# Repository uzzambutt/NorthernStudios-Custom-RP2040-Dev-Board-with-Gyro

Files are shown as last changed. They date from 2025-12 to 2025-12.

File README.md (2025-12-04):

# NorthernStudios-Custom-RP2040-Dev-Board-with-Gyro

***Schematic***
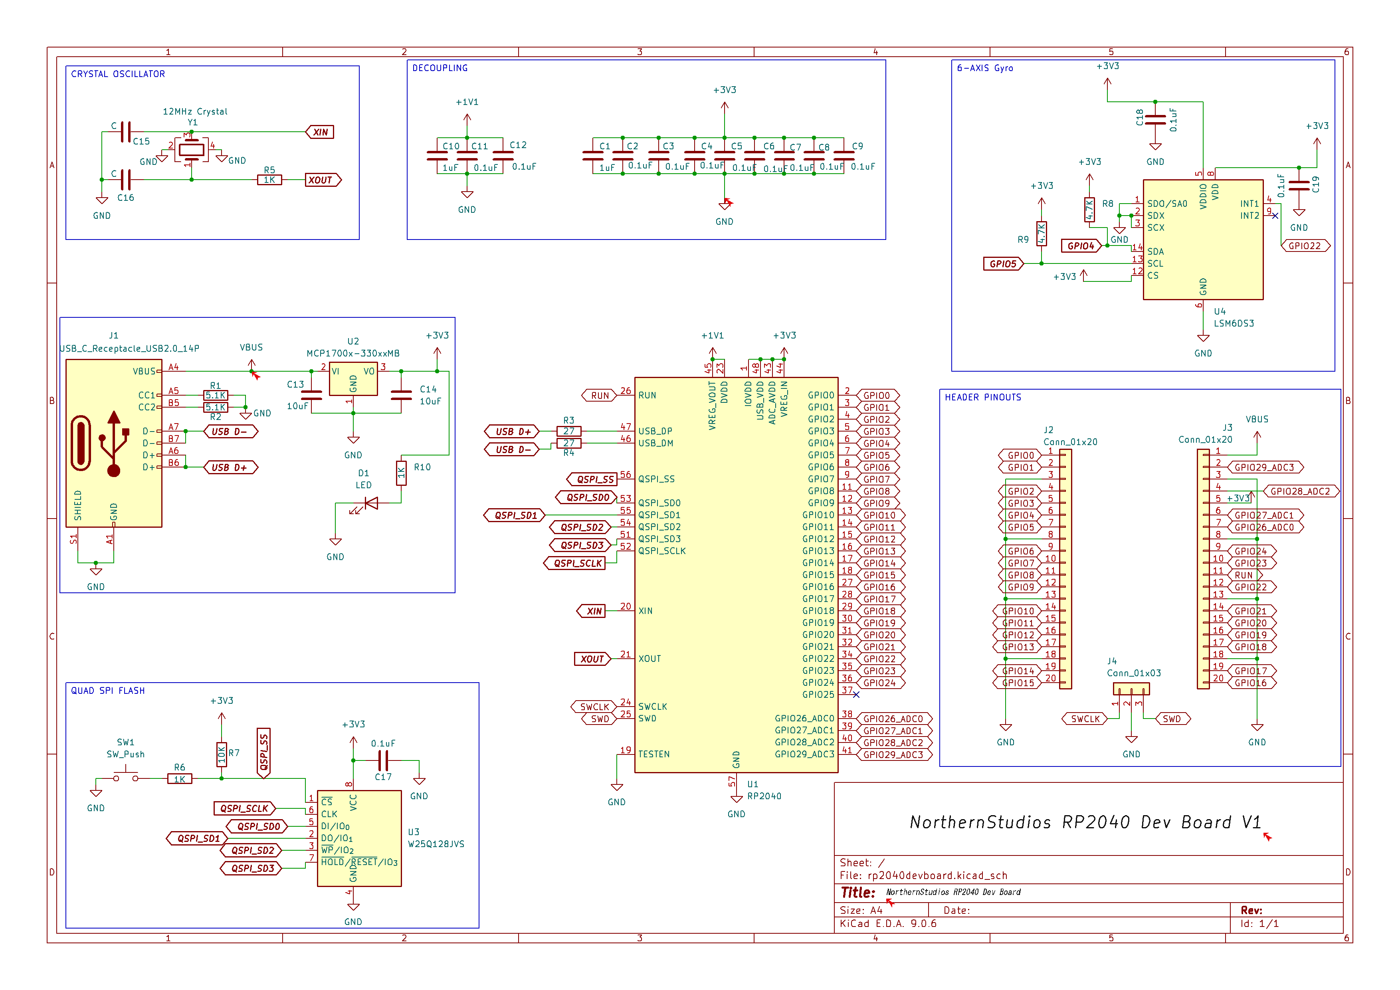
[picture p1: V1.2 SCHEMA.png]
Schematic


## Images:
**Rendered Board**:
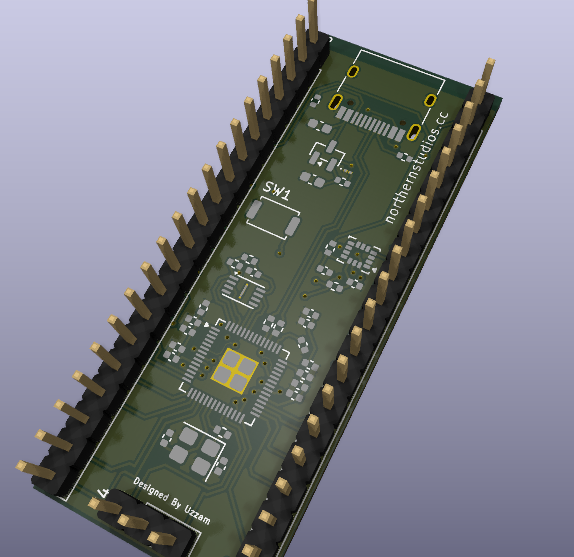
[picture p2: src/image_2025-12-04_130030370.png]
Rendered


**Raw Routing**:
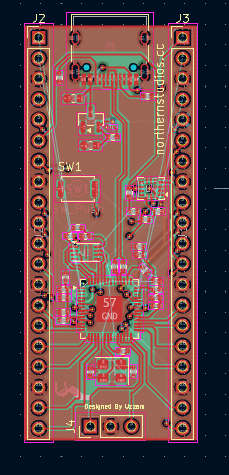
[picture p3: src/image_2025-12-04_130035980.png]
Routing


## Features
1: This dev board has a LED for power indicator.
2: This board has a 6-Axis Gyro + Accelerometer integrated in it. you can read the schematic to check it out.

## Caution:
> I have not routed the GPIO 0,1 and ADC 1 and 2 because of spacing problems. there was not enough space to route them because the accelerometer had covered most of that space. 

---
> Made By uzzam for NorthernStudios.
> Funded By HackClub.
> 04/12/2025
> uzzambutt1@outlook.com

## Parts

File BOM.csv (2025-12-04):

Reference | Qty | Value | DNP | Exclude from BOM | Exclude from Board | Footprint | Datasheet
C1,C10 | 2 | 1uF |  |  |  | Capacitor_SMD:C_0402_1005Metric | ~
C2,C3,C4,C5,C6,C7,C8,C9,C11,C12,C17,C18,C19 | 13 | 0.1uF |  |  |  | Capacitor_SMD:C_0402_1005Metric | ~
C13,C14 | 2 | 10uF |  |  |  | Capacitor_SMD:C_0603_1608Metric | ~
C15,C16 | 2 | 33pF |  |  |  | Capacitor_SMD:C_0402_1005Metric | ~
D1 | 1 | LED |  |  |  | LED_SMD:LED_01005_0402Metric | ~
J1 | 1 | USB_C_Receptacle_USB2.0_14P |  |  |  | Connector_USB:USB_C_Receptacle_HRO_TYPE-C-31-M-12 | https://www.usb.org/sites/default/files/documents/usb_type-c.zip
J2,J3 | 2 | Conn_01x20 |  |  |  | Connector_PinHeader_2.54mm:PinHeader_1x20_P2.54mm_Vertical | ~
J4 | 1 | Conn_01x03 |  |  |  | Connector_PinHeader_2.54mm:PinHeader_1x03_P2.54mm_Vertical | ~
R1,R2 | 2 | 5.1K |  |  |  | Resistor_SMD:R_0402_1005Metric | ~
R3,R4 | 2 | 27 |  |  |  | Resistor_SMD:R_0402_1005Metric | ~
R5,R6,R10 | 3 | 1K |  |  |  | Resistor_SMD:R_0402_1005Metric | ~
R7 | 1 | 10K |  |  |  | Resistor_SMD:R_0402_1005Metric | ~
R8,R9 | 2 | 4.7K |  |  |  | Resistor_SMD:R_0402_1005Metric | ~
SW1 | 1 | SW_Push |  |  |  | Button_Switch_SMD:SW_Push_SPST_NO_Alps_SKRK | ~
U1 | 1 | RP2040 |  |  |  | Package_DFN_QFN:QFN-56-1EP_7x7mm_P0.4mm_EP3.2x3.2mm | https://datasheets.raspberrypi.com/rp2040/rp2040-datasheet.pdf
U3 | 1 | W25Q16JVZPIQ TR |  |  |  | Package_SON:Winbond_USON-8-1EP_3x2mm_P0.5mm_EP0.2x1.6mm | https://www.winbond.com/resource-files/w25q128jv_dtr%20revc%2003272018%20plus.pdf
U4 | 1 | LSM6DS3 |  |  |  | Package_LGA:LGA-14_3x2.5mm_P0.5mm_LayoutBorder3x4y | https://www.st.com/resource/en/datasheet/lsm6ds3tr-c.pdf
U5 | 1 | MCP1700x-330xxTT |  |  |  | Package_TO_SOT_SMD:SOT-23 | http://ww1.microchip.com/downloads/en/DeviceDoc/20001826D.pdf
Y1 | 1 | 12MHz Crystal |  |  |  | Crystal:Crystal_SMD_3225-4Pin_3.2x2.5mm | ~

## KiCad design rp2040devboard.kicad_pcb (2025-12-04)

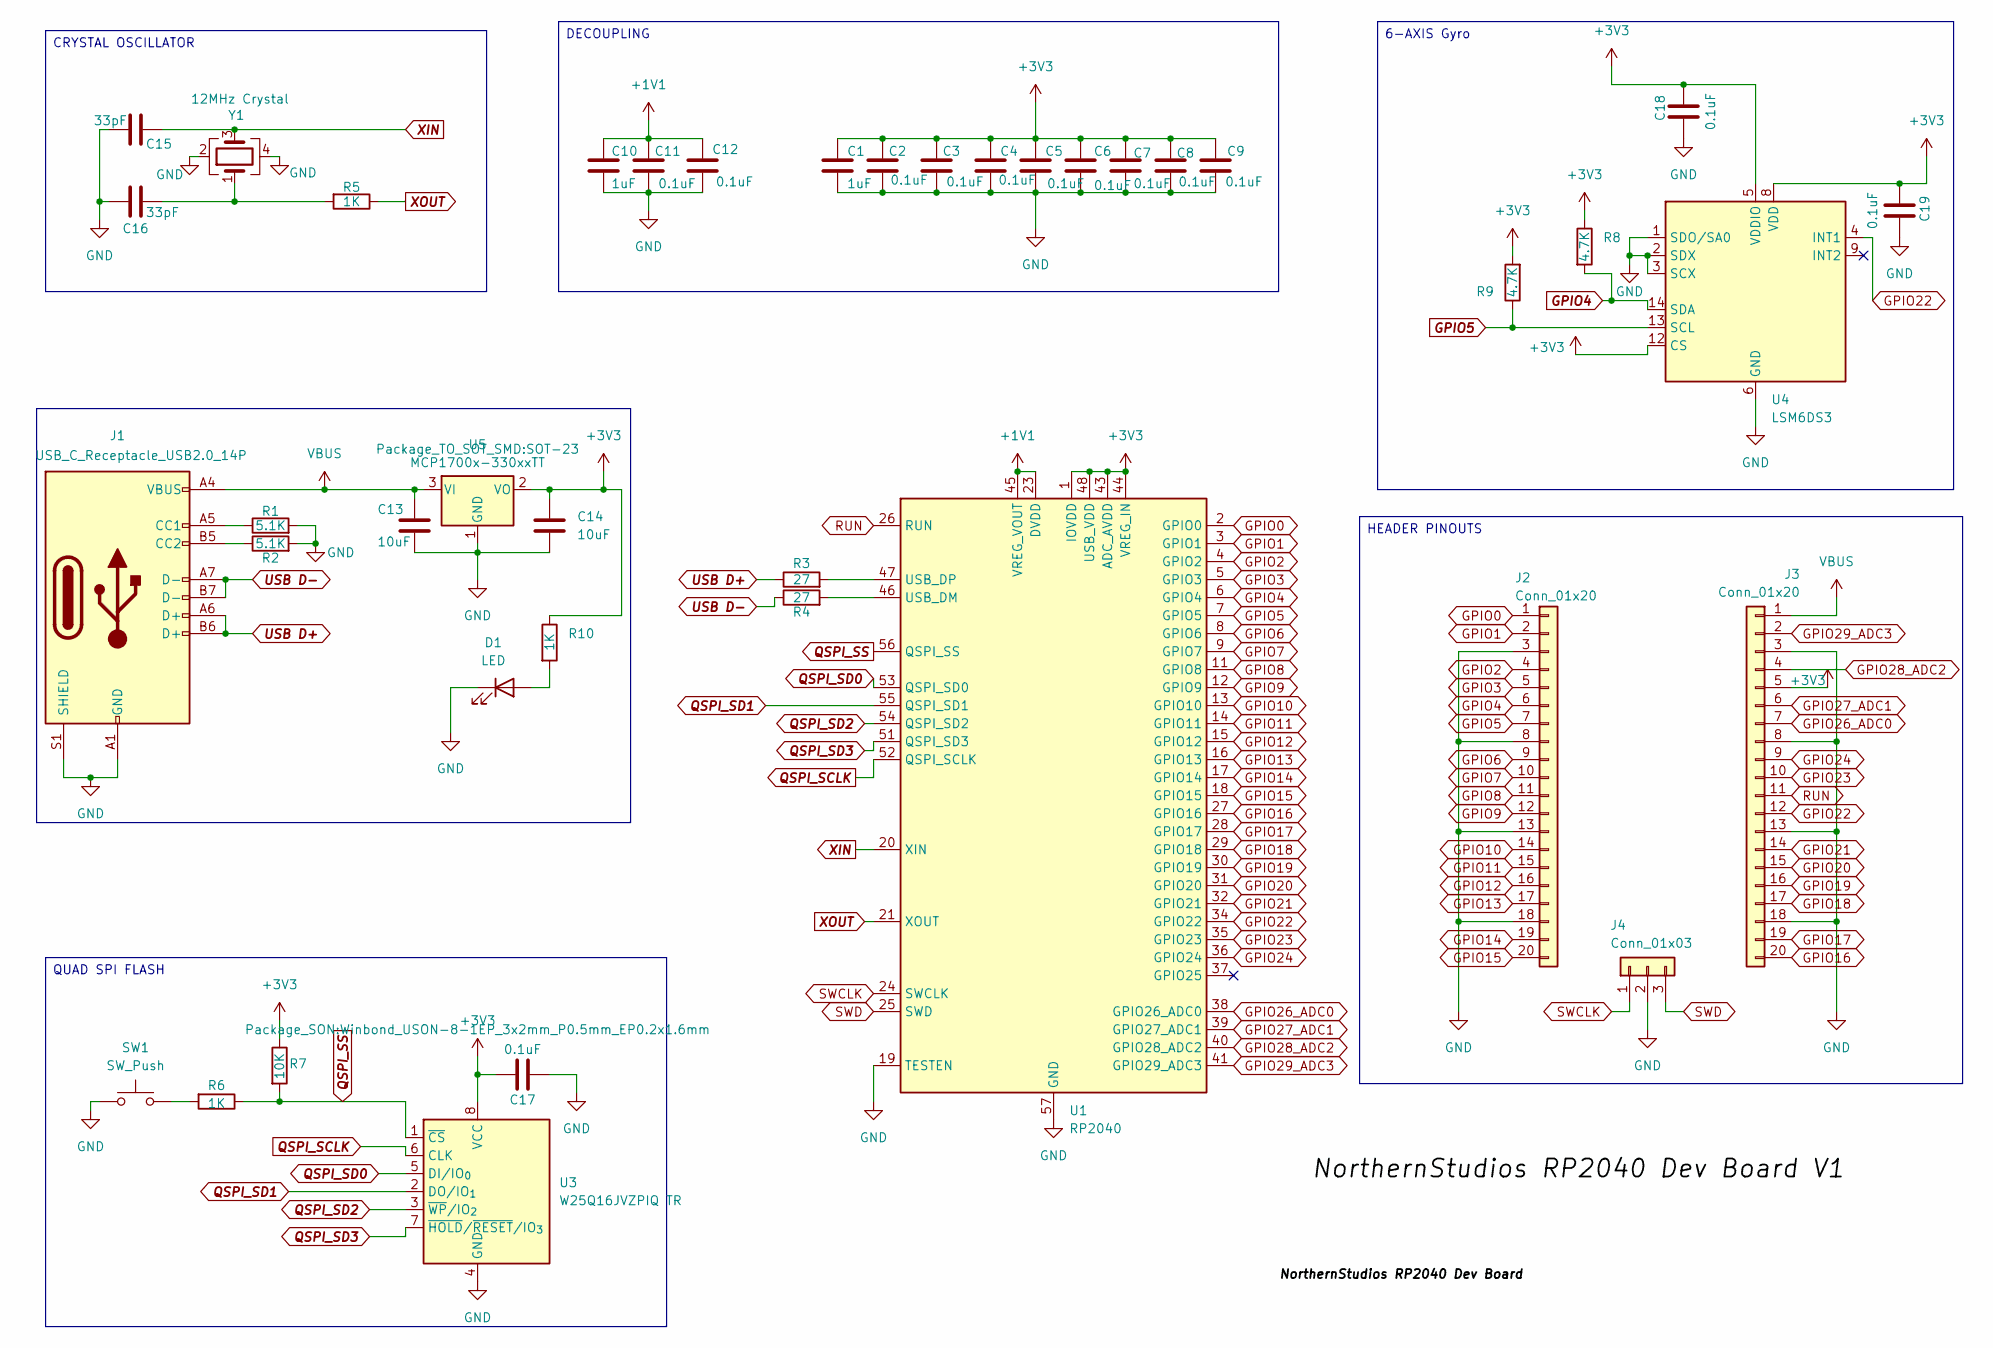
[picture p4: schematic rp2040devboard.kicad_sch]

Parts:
C1, C10: 1uF; C_0402_1005Metric
C2, C3, C4, C5, C6, C7, C8, C9, C11, C12, C17, C18, C19: 0.1uF; C_0402_1005Metric
C13, C14: 10uF; C_0603_1608Metric
C15, C16: 33pF; C_0402_1005Metric
D1: LED; LED_01005_0402Metric
J1: USB_C_Receptacle_USB2.0_14P; USB_C_Receptacle_HRO_TYPE-C-31-M-12
J2, J3: Conn_01x20; PinHeader_1x20_P2.54mm_Vertical
J4: Conn_01x03; PinHeader_1x03_P2.54mm_Vertical
R1, R2: 5.1K; R_0402_1005Metric
R3, R4: 27; R_0402_1005Metric
R5, R6, R10: 1K; R_0402_1005Metric
R7: 10K; R_0402_1005Metric
R8, R9: 4.7K; R_0402_1005Metric
SW1: SW_Push; SW_Push_SPST_NO_Alps_SKRK
U1: RP2040; QFN-56-1EP_7x7mm_P0.4mm_EP3.2x3.2mm
U3: W25Q16JVZPIQ TR; Winbond_USON-8-1EP_3x2mm_P0.5mm_EP0.2x1.6mm
U4: LSM6DS3; LGA-14_3x2.5mm_P0.5mm_LayoutBorder3x4y
U5: MCP1700x-330xxTT; SOT-23
Y1: 12MHz Crystal; Crystal_SMD_3225-4Pin_3.2x2.5mm

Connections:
+1V1: C10.1, C11.1, C12.1, U1.23 (DVDD), U1.45 (VREG_VOUT), U1.50 (DVDD)
+3V3: C1.1, C2.1, C3.1, C4.1, C5.1, C6.1, C7.1, C8.1, C9.1, C14.1, C17.1, C18.1, C19.2, J3.5, R7.1, R8.1, R9.2, R10.1, U1.1 (IOVDD), U1.10 (IOVDD), U1.22 (IOVDD), U1.33 (IOVDD), U1.42 (IOVDD), U1.43 (ADC_AVDD), U1.44 (VREG_IN), U1.48 (USB_VDD), U1.49 (IOVDD), U3.8 (VCC), U4.5 (VDDIO), U4.8 (VDD), U4.12 (CS), U5.2 (VO)
GND: C1.2, C2.2, C3.2, C4.2, C5.2, C6.2, C7.2, C8.2, C9.2, C10.2, C11.2, C12.2, C13.1, C14.2, C15.1, C16.1, C17.2, C18.2, C19.1, D1.1 (K), J1.A1 (GND), J1.A12 (GND), J1.B1 (GND), J1.B12 (GND), J1.S1 (SHIELD), J2.3, J2.8, J2.13, J2.18, J3.3, J3.8, J3.13, J3.18, J4.2, R1.2, R2.2, SW1.1, U1.19 (TESTEN), U1.57 (GND), U3.4 (GND), U4.1 (SDO/SA0), U4.2 (SDX), U4.3 (SCX), U4.6 (GND), U4.7 (GND), U5.1 (GND), Y1.2, Y1.4
GPIO0: J2.1, U1.2 (GPIO0)
GPIO1: J2.2, U1.3 (GPIO1)
GPIO2: J2.4, U1.4 (GPIO2)
GPIO3: J2.5, U1.5 (GPIO3)
GPIO4: J2.6, R8.2, U1.6 (GPIO4), U4.14 (SDA)
GPIO5: J2.7, R9.1, U1.7 (GPIO5), U4.13 (SCL)
GPIO6: J2.9, U1.8 (GPIO6)
GPIO7: J2.10, U1.9 (GPIO7)
GPIO8: J2.11, U1.11 (GPIO8)
GPIO9: J2.12, U1.12 (GPIO9)
GPIO10: J2.14, U1.13 (GPIO10)
GPIO11: J2.15, U1.14 (GPIO11)
GPIO12: J2.16, U1.15 (GPIO12)
GPIO13: J2.17, U1.16 (GPIO13)
GPIO14: J2.19, U1.17 (GPIO14)
GPIO15: J2.20, U1.18 (GPIO15)
GPIO16: J3.20, U1.27 (GPIO16)
GPIO17: J3.19, U1.28 (GPIO17)
GPIO18: J3.17, U1.29 (GPIO18)
GPIO19: J3.16, U1.30 (GPIO19)
GPIO20: J3.15, U1.31 (GPIO20)
GPIO21: J3.14, U1.32 (GPIO21)
GPIO22: J3.12, U1.34 (GPIO22), U4.4 (INT1)
GPIO23: J3.10, U1.35 (GPIO23)
GPIO24: J3.9, U1.36 (GPIO24)
GPIO26_ADC0: J3.7, U1.38 (GPIO26_ADC0)
GPIO27_ADC1: J3.6, U1.39 (GPIO27_ADC1)
GPIO28_ADC2: J3.4, U1.40 (GPIO28_ADC2)
GPIO29_ADC3: J3.2, U1.41 (GPIO29_ADC3)
unnamed: C16.2, R5.2, Y1.1
unnamed: D1.2 (A), R10.2
unnamed: J1.A5 (CC1), R1.1
unnamed: J1.B5 (CC2), R2.1
unnamed: R6.2, SW1.2
unnamed: R4.2, U1.46 (USB_DM)
unnamed: R3.2, U1.47 (USB_DP)
QSPI_SCLK: U1.52 (QSPI_SCLK), U3.6 (CLK)
QSPI_SD0: U1.53 (QSPI_SD0), U3.5 (DI/IO_{0})
QSPI_SD1: U1.55 (QSPI_SD1), U3.2 (DO/IO_{1})
QSPI_SD2: U1.54 (QSPI_SD2), U3.3 (~WP/IO_{2})
QSPI_SD3: U1.51 (QSPI_SD3), U3.7 (~HOLD/~RESET/IO_{3})
QSPI_SS: R6.1, R7.2, U1.56 (QSPI_SS), U3.1 (~CS)
RUN: J3.11, U1.26 (RUN)
SWCLK: J4.1, U1.24 (SWCLK)
SWD: J4.3, U1.25 (SWD)
USB D+: J1.A6 (D+), J1.B6 (D+), R3.1
USB D-: J1.A7 (D-), J1.B7 (D-), R4.1
VBUS: C13.2, J1.A4 (VBUS), J1.A9 (VBUS), J1.B4 (VBUS), J1.B9 (VBUS), J3.1, U5.3 (VI)
XIN: C15.2, U1.20 (XIN), Y1.3
XOUT: R5.1, U1.21 (XOUT)

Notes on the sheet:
QUAD SPI FLASH
HEADER PINOUTS
DECOUPLING
6-AXIS Gyro
CRYSTAL OSCILLATOR

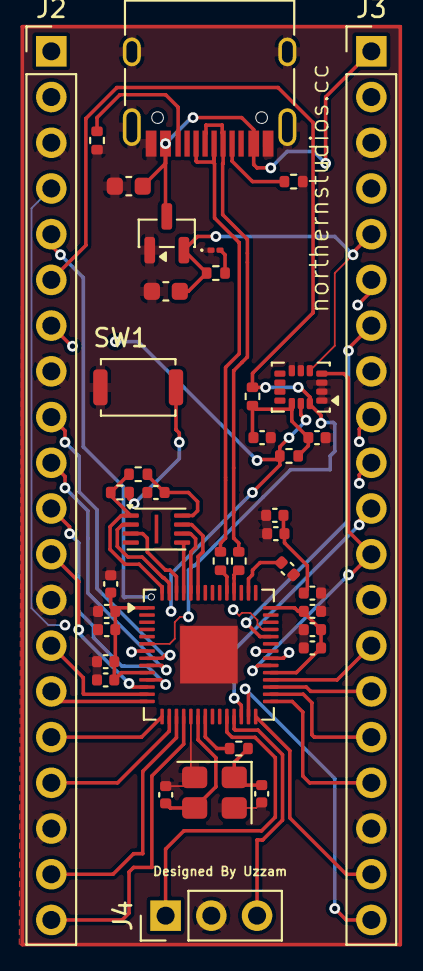
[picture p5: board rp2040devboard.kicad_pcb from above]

Board: 6 copper layers, 40 parts (0 on the bottom side), 53 nets.
